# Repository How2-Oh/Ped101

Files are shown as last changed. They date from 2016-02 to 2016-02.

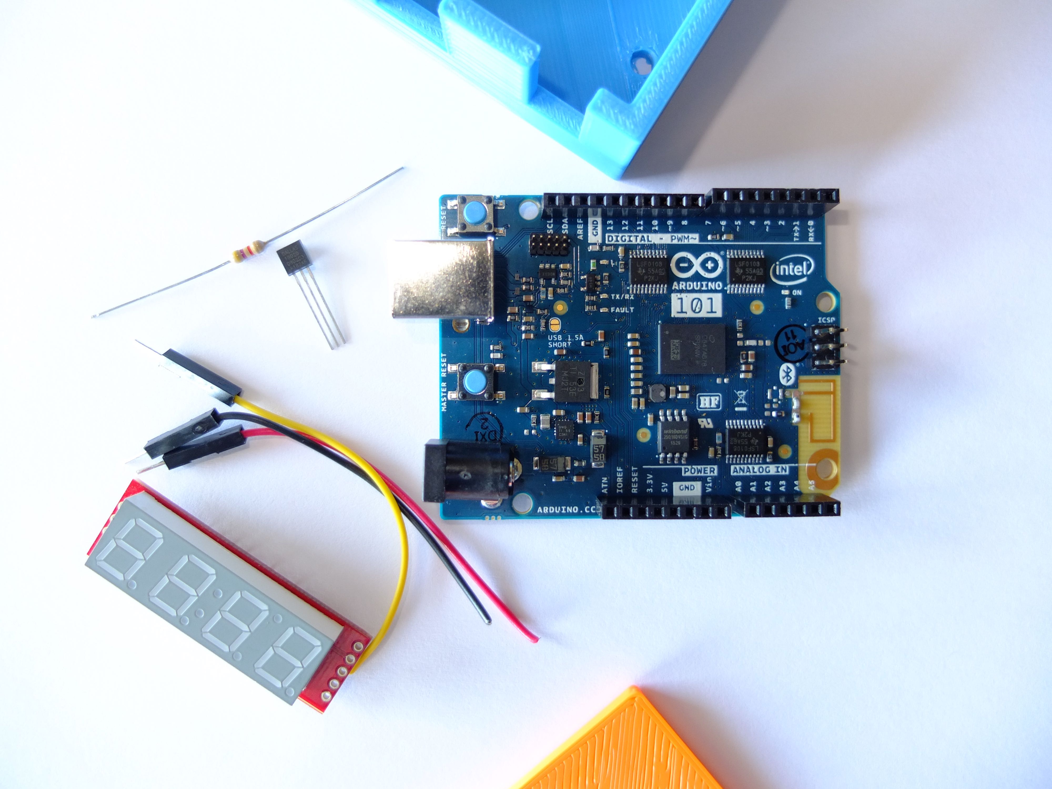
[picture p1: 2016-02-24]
Pix/Ped101_Parts.jpg

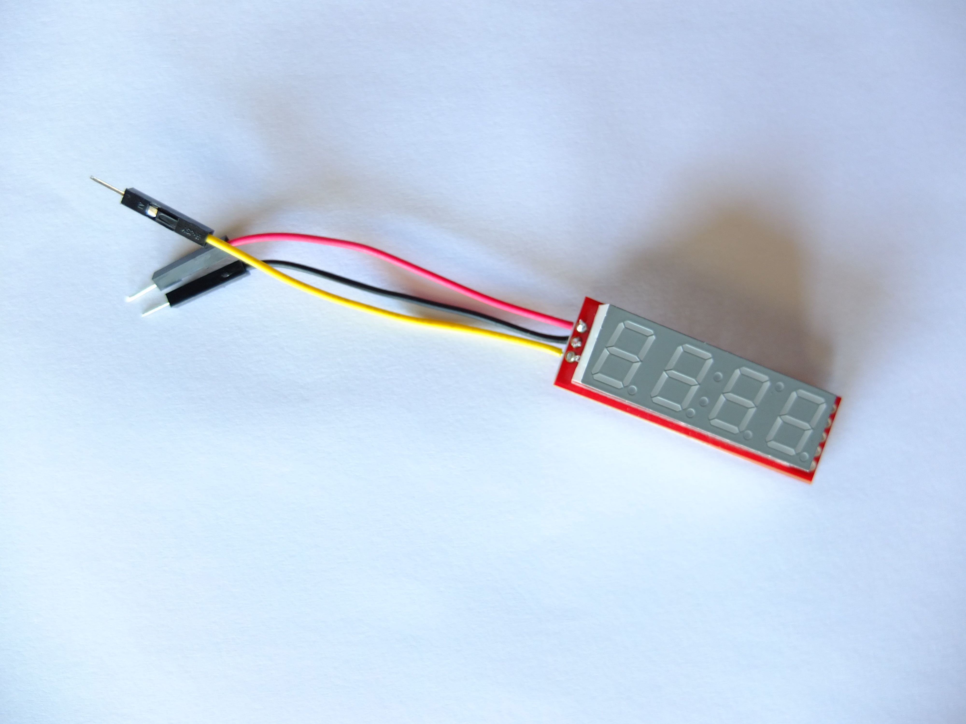
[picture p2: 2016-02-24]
Pix/Display_Wiring.jpg

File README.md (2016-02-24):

# Ped101
A practice pedometer built on the Arduino 101.

What happens when you combine an Intel 32-bit Quark microcontroller with an open-source Arduino board? You get the Arduino 101. Known as the Intel Curie Compute Module, the Quark microcontroller is supported by a Bluetooth Low Energy radio and a dual combo 6-axis accelerometer and gyroscope sensor package. This combo sensor is the Bosch BMI160. Likewise, these dual sensors can be used in concert as an Inertial Monitoring Device (IMU) for measuring orientation and angular veloctiy.

See Intel for more information:
<a href=intel.com/content/www/us/en/do-it-yourself/arduino-101.html>intel.com/content/www/us/en/do-it-yourself/arduino-101.html</a>

A real-world application for this IMU technology is in a pedometer. If you're a runner or a racewalker, then you will log a lot of practice miles before each competitive event. While your training regimen can be broken down into many different phases (e.g., stamina, endurance, heart rate, etc.), the most basic form of practice will be just logging easy miles each day. In this form of practice, all you care about is distance and time. Thankfully, both of these measurements can be recorded easily with the Arduino 101's IMU.

Since we will be using the Curie Compute Module for counting steps, the IMU will only be using the accelerometer portion of the Bosch sensor. There is a special Arduino library, CurieImu that makes the initialization and use of the IMU very easy.

This project is called Ped101.

In addition to the Arduino 101 IMU, Ped101 will also display the current ambient temperature. This data is obtained from a Dallas Semiconductor DS18B20 one-wire temperature sensor. A four-digit, serial 7-segment LED display is used for conveying these data to the runner. There are four updated data displays: steps, distance (in hundredths of a mile), time (in seconds), and temperature (in degrees Fahrenheit). Finally, a 9V battery is used for powering Ped101.

##Parts
<ul>
<li>Arduino 101 (SparkFun Electronics DEV-13787)
<li>DS18B20 One-Wire temperature sensor (SFE SEN-00245)
<li>Serial four-digit, 7-segment LED display (SFE COM-11443)
<li>3 - Male-Male jumper wires (SFE PRT-12795)
<li>4.7K resistor (Mouser Yageo; mouser.com)
<li>9V battery & barrel connector (SFE PRT-10512 or, littleBits power connector)
</ul>
Three 3D printable STL files:
<ul>
<li>Box
<li>Lid
<li>Straps & washers (for mounting Ped101 on hand grip or belt)
<li>4x40 mounting hardware
</ul>
<b>NOTE:</b> The serial LED display used for Ped101 has been updated and the new version might not fit inside the 3D printed lid.

##Step-by-Step

1. Mount the serial display and the DS18B20 sensor to the Ped101 lid. Testors Cement for Plastic Models No. 3512 works.

2. Snip the jumper wires in half and solder three wires to the serial connections on the LED display.

3. Solder the 4.7K resistor between the DQ (#2) and VDD (#3) legs of the DS18B20.

4. Solder the remaining three wires to the three legs of the DS18B20.

5. Plug the male ends of each jumper wire into the Arduino 101 like so:

<ul>
<li>Arduino 3.3V - Serial 7-Segment VCC
<li>Arduino GND - Serial 7-Segment GND 
<li>Arduino 8 - Serial 7-Segment RX
</ul>
<ul>
<li>Arduino 5V - DS18B20 VDD (pin #3)
<Li>Arduino 10 - DS18B20 DQ (pin #2)
<li>Arduino GND - DS18B20 GND (pin #1)
</ul>

6. Enter your stride length in the Arduino code at the appropriate variable. This length is measured in inches.

7. Attach the Arduino 101 to your computer and upload the Ped101 code to the device.

8. Drop the Arduino 101 into the 3D printed box and secure the washers and straps on the backside of the box and through the Arduino with the 4-40 mounting hardware.

9. Mount the lid on the box. Again, Testors cement works well for this step.

10. Plug the battery into the Arduino 101 and enjoy your run.

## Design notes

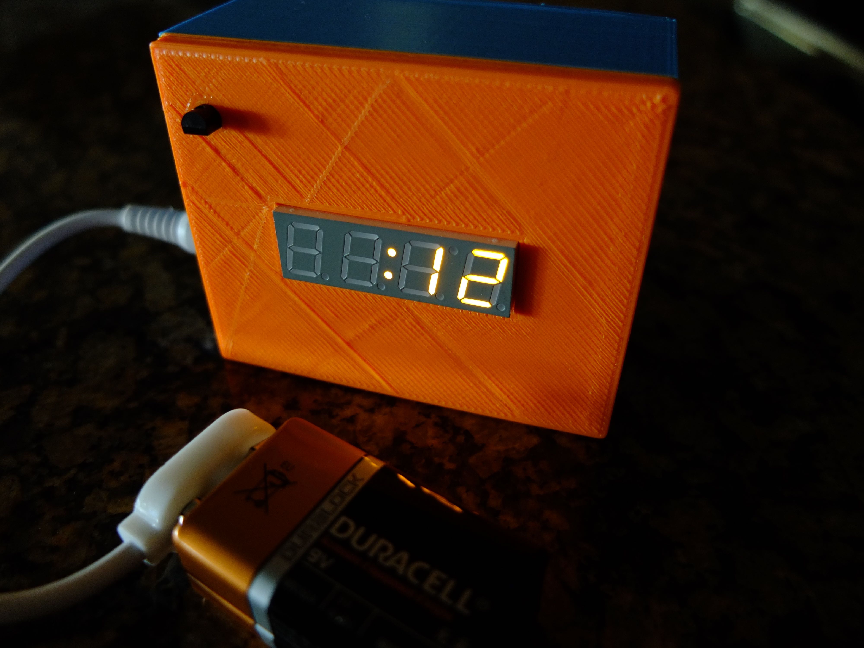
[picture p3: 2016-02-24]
Pix/Time_DIsplay.jpg

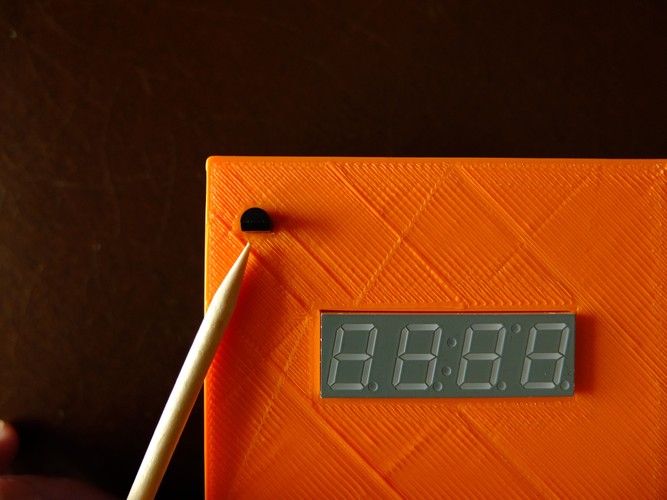
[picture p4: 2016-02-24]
Pix/Temp_Sensor.jpg

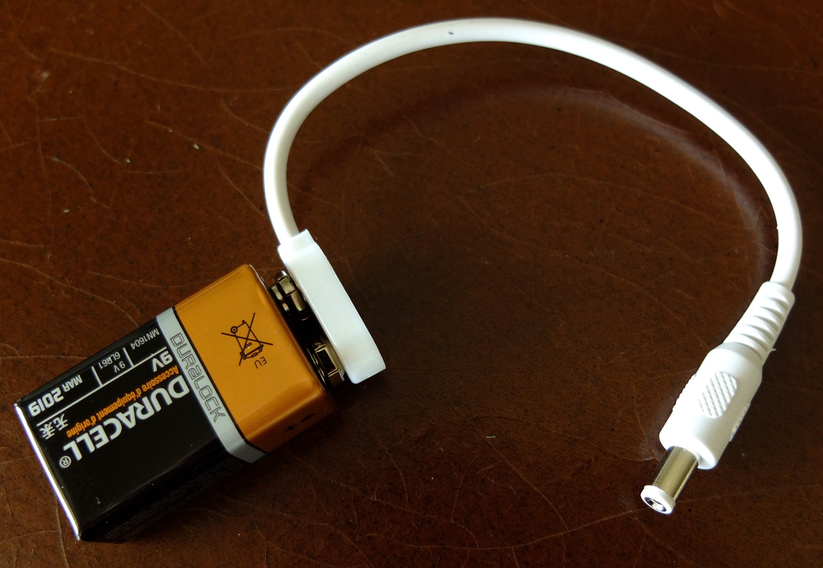
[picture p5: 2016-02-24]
Pix/Battery_Connector.jpg

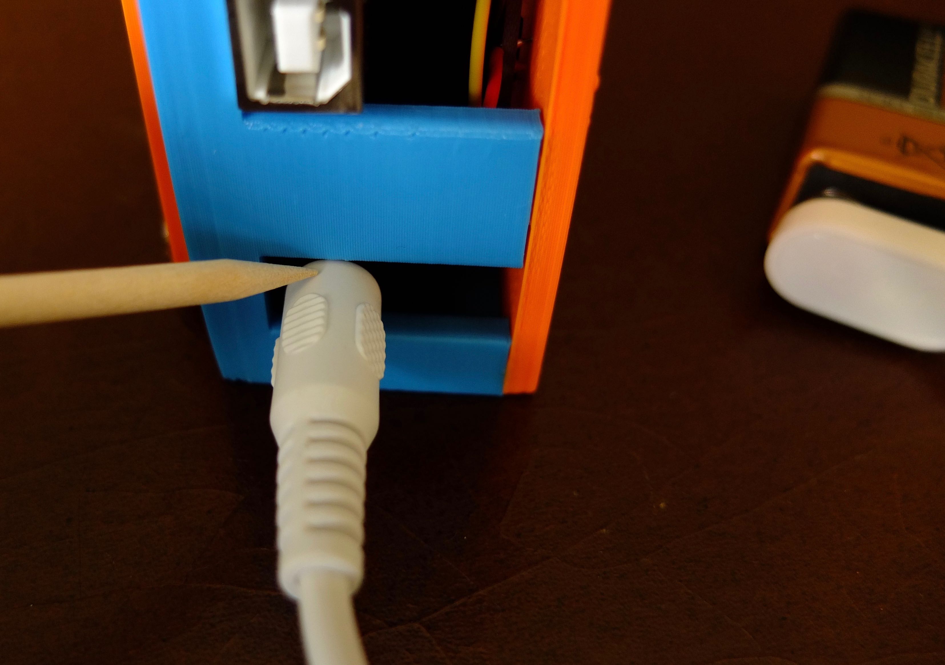
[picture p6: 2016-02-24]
Pix/Battery_Plug.jpg

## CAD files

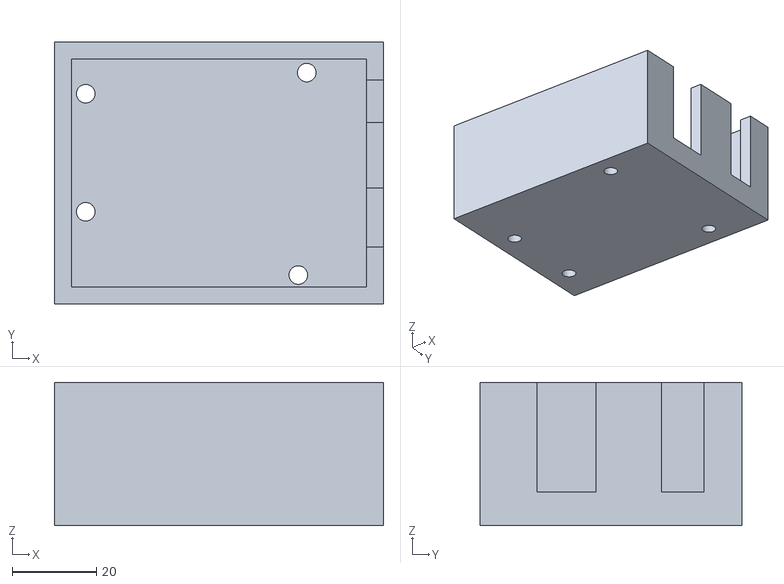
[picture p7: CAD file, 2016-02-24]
3DFiles/Ped101_Box.stl
78.0 x 62.0 x 34.0

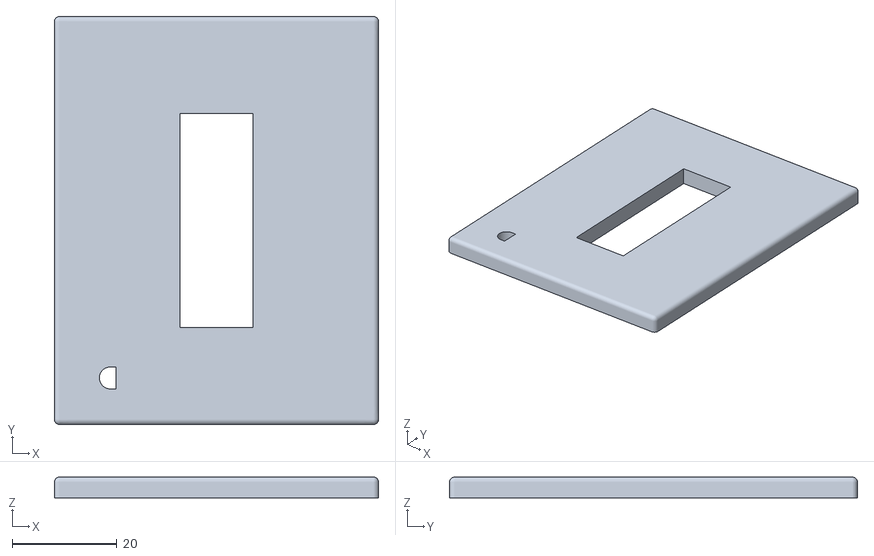
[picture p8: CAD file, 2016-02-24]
3DFiles/Ped101_Lid.stl
62.0 x 78.0 x 4.00

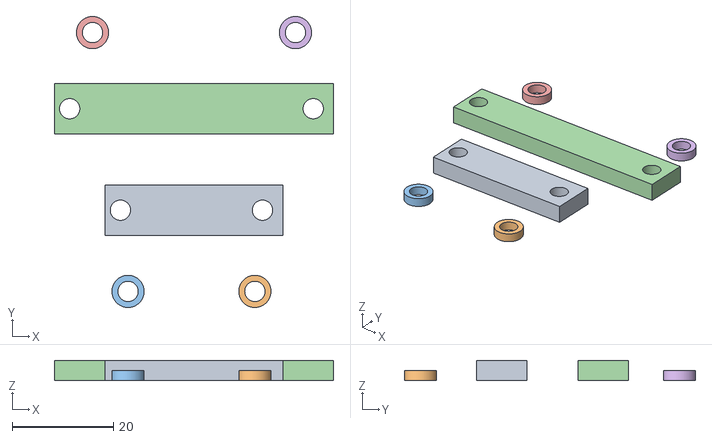
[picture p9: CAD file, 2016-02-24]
3DFiles/Straps_Washers.stl
55.0 x 57.3 x 4.00

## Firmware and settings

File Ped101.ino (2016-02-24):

/* Pedometer101
 *  
 *  Based on the following libraries:
 *  Serial 7-Segment
   SparkFun Electronics
   date: November 27, 2012
   license: This code is public domain.

  OneWire DS18B20 Thermometer

* Copyright (c) 2015 Intel Corporation.  All rights reserved.
  *
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
 * This sketch example demonstrates how the BMI160 accelerometer on the
 * Intel(R) Curie(TM) module can be used as a Step Counter (pedometer)

This example code shows how you could use software serial Arduino 
library to interface with a Serial 7-Segment Display.

Circuit:
Arduino -------------- Serial 7-Segment
3.3V ------------------ VCC 
GND ------------------- GND 
8 --------------------- RX

DS18B20:
Arduino --------------- DS18B20
5V -------------------- VDD (pin #3)
10 -------------------- DQ (pin #2)
GND ------------------- GND (pin #1)
5V -- 4.7K resistor --- DQ (pin #2)
*/

#include <SoftwareSerial.h>
#include "CurieImu.h"
#include <OneWire.h>

// Pedometer step count variable
int lastStepCount = 0;

// These are the Arduino pins required to create a software seiral 
// instance. Software serial is used with the 4-Segment LED display.
// We'll actually only use the TX pin.
const int softwareTx = 8;
const int softwareRx = 7;

SoftwareSerial s7s(softwareRx, softwareTx);

unsigned int counter = 0; // This variable will count up to 65k
char tempString[10]; // Will be used with sprintf to create strings

int i = 0; // An increment timing variable for use during display

OneWire  ds(10);  // Thermometer is on pin 10 (a 4.7K resistor is necessary)

void setup()
{
  // Must begin s7s software serial at the correct baud rate. 
  // The default of the s7s is 9600.
  s7s.begin(9600);

  // Set brightness value at the sketch beginning 
  setBrightness(0); // Highest brightness 

  setDecimals(0b1111111); // Turn on all decimals, colon, apos

  // Countdown to start
  for (i=0; i<500; i++) {
    s7s.print("3333");
  }
  for (i=0; i<500; i++) {
    s7s.print("2222");
  }
  for (i=0; i<500; i++) {
    s7s.print("1111");
  }

  clearDisplay();
  setDecimals(0b0000000); // Turn off all decimals, colon, apos

  // Setup the A101
  CurieImu.initialize(); // initialise the IMU
  CurieImu.setStepDetectionMode(BMI160_STEP_MODE_NORMAL); // set step detection mode to normal
  CurieImu.setStepCountEnabled(true); // enable step count

}

void loop() 
{
  // Check the step count
  updateStepCount();

  // Use the step count to find the distance
  updateDistance();

  // Display the time
  updateTime();

  // Display the temperature
  updateTemp();
  
}

// Send the clear display command (0x76)
// This will clear 
void clearDisplay() 
{
s7s.write(0x76);
}

// Sets the LED display brightness. Should receive byte with the value
// to set the brightness to
// dimmest------------->brightest 
// 255--------127--------0 
void setBrightness(byte value)
{
s7s.write(0x7A); // Set brightness command byte
s7s.write(value); // brightness data byte 
}

// Sends Content to the display.
void sendContent(byte decimals)
{
//s7s.write();
//s7s.write(decimals);
}

// Turn on any, none, or all of the decimals.
// The six lowest bits in the decimals parameter sets a decimal 
// (or colon, or apostrophe) on or off. A 1 indicates on, 0 off.
// The colon uses two bits. 
// [MSB] (X)(X)(Apos)(Colon)(Colon)(Digit 4)(Digit 3)(Digit2)(Digit1) 
void setDecimals(byte decimals)
{
s7s.write(0x77);
s7s.write(decimals);
}

// Determine step count and display total
void updateStepCount()
{
  int stepCount = CurieImu.getStepCount(); // set stepCount to read stepCount from function
  if (stepCount != lastStepCount) { // if stepCount has changed
    setDecimals(0b0000001); // Sets digit 1 decimal point on - this indicates the Step count on the display

    // Use sprintf to create a string to send to the s7s. 
    // The %4d option creates a 4-digit integer. 
    sprintf(tempString, "%4d", stepCount);

    // Output the tempString to the S7S 
    for (i=0; i<500; i++) {
      s7s.print(tempString);
    }

  lastStepCount = stepCount;

  setDecimals(0b0000000); // Turn off all decimals, colon, apos

   }
}

// Determine the distance travelled and display total
void updateDistance()
{

  int distance = 0;  // Total distance travelled
  int distanceTenths = 0;  // Tenths of a mile travelled

  int stride = 35;  // Enter your stride length in inches
  char stringTenths[4]; // Used for making printable tenths of a mile
  
/*
  Sliding Stride Scale (based on height)
  0-2 steps = height/5
  2-3 steps = height/4
  3-4 steps = height/3
  4-5 steps = height/2
  5-6 steps = height/1.2
  6-8 steps = height
  >=8 steps = height * 1.2
  lastStepCount from CurieIMU = steps
  Distance = number of steps * distance per step (stride)
 */

    setDecimals(0b0000010); // Sets digit 2 decimal point on - this indicates the Distance on the display

    distance = lastStepCount * stride; // This is distance measured in inches
    distanceTenths = (((distance) / 12) % 5280 / 100);

    // Use sprintf to create a string to send to the s7s. 
    // The %4d option creates a 4-digit integer. 
    sprintf(stringTenths, "%4d", distanceTenths);

    // Output the tempString to the S7S 
    for (i=0; i<500; i++) {
      s7s.print(stringTenths);
    }
    setDecimals(0b0000000); // Turn off all decimals, colon, apos
}

// Determine pace and display total
void updateTime()
{
  unsigned long totalSeconds = millis();

  totalSeconds = ((totalSeconds / 1000) / 60);

    setDecimals(0b0110000); // Sets colon points on - this indicates the time on the display

    // Use sprintf to create a string to send to the s7s. 
    // The %4lu option creates a 4-digit unsigned long. 
    sprintf(tempString, "%4lu", totalSeconds);

    // Output the tempString to the S7S 
    for (i=0; i<500; i++) {
      s7s.print(tempString);
    }
    setDecimals(0b0000000); // Turn off all decimals, colon, apos

}

// Grab the temperature from the sensor and display the degrees in F
void updateTemp()
{
  byte j;
  byte present = 0;
  byte type_s;
  byte data[12];
  byte addr[8];
  float celsius, fahrenheit;
  
  if ( !ds.search(addr)) {
    ds.reset_search();
    delay(250);
    return;
  }
  
  for( j = 0; j < 8; j++) {
  }

  if (OneWire::crc8(addr, 7) != addr[7]) {
      return;
  }
 
  // the first ROM byte indicates which chip
  switch (addr[0]) {
    case 0x10:
      //Serial.println("  Chip = DS18S20");  // or old DS1820
      type_s = 1;
      break;
    case 0x28:
      //Serial.println("  Chip = DS18B20");
      type_s = 0;
      break;
    case 0x22:
      //Serial.println("  Chip = DS1822");
      type_s = 0;
      break;
    default:
      //Serial.println("Device is not a DS18x20 family device.");
      return;
  } 

  ds.reset();
  ds.select(addr);
  ds.write(0x44, 1);        // start conversion, with parasite power on at the end
  
  delay(1000);     // maybe 750ms is enough, maybe not
  // we might do a ds.depower() here, but the reset will take care of it.
  
  present = ds.reset();
  ds.select(addr);    
  ds.write(0xBE);         // Read Scratchpad

  for ( j = 0; j < 9; j++) {           // we need 9 bytes
    data[j] = ds.read();
  }

  // Convert the data to actual temperature
  // because the result is a 16 bit signed integer, it should
  // be stored to an "int16_t" type, which is always 16 bits
  // even when compiled on a 32 bit processor.
  int16_t raw = (data[1] << 8) | data[0];
  if (type_s) {
    raw = raw << 3; // 9 bit resolution default
    if (data[7] == 0x10) {
      // "count remain" gives full 12 bit resolution
      raw = (raw & 0xFFF0) + 12 - data[6];
    }
  } else {
    byte cfg = (data[4] & 0x60);
    // at lower res, the low bits are undefined, so let's zero them
    if (cfg == 0x00) raw = raw & ~7;  // 9 bit resolution, 93.75 ms
    else if (cfg == 0x20) raw = raw & ~3; // 10 bit res, 187.5 ms
    else if (cfg == 0x40) raw = raw & ~1; // 11 bit res, 375 ms
    //// default is 12 bit resolution, 750 ms conversion time
  }

  celsius = (float)raw / 16.0;
  fahrenheit = celsius * 1.8 + 32.0;

    setDecimals(0b1000000); // Sets apos point on - this indicates the temp on the display
    // Use sprintf to create a string to send to the s7s. 
    // The %3.1f option creates a 1-decimal float. 
    sprintf(tempString, "%3.1f", fahrenheit);

    // Output the tempString to the S7S 
    for (i=0; i<500; i++) {
      s7s.print(tempString);
    }
    setDecimals(0b0000000); // Turn off all decimals, colon, apos
}
